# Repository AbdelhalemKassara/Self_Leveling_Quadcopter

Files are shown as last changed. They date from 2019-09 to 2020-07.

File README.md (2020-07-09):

# Self Leveling Quadcopter
As you can tell by the title this project is a self leveling quadcopter that I built using an Arduino Uno. This project is just something that I wanted to try to build for fun and to see if I could make a semi functional drone that has a functional self leveling feature. I have writen 2 versions of the code Manual and SelfLevel. Manual you use the joystick to change the amount of power going to each motor. Self Level you use the joystick to change the tilt angle and the arduino does all the leveling for you.

## Photos and Videos
[Video of the Drone Flying](https://youtu.be/ctLI9JnbgVA)

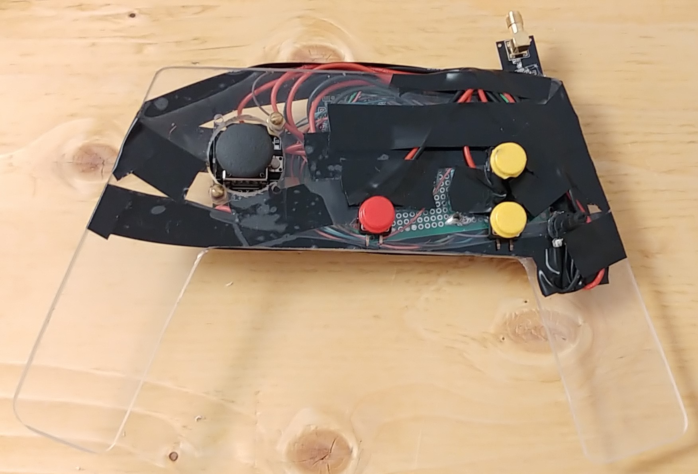
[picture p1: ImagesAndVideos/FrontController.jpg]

>Front of the controller

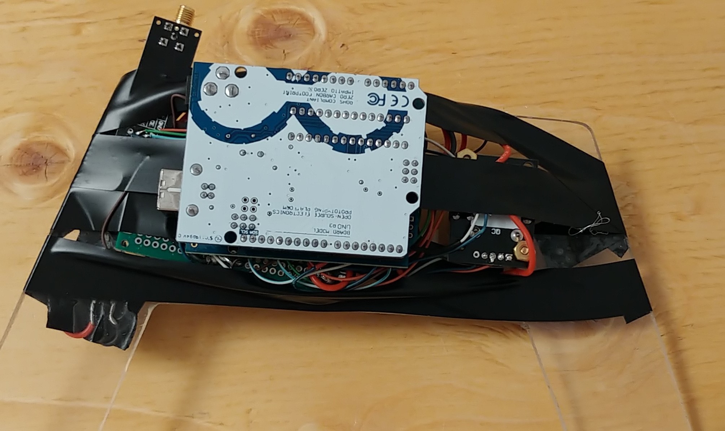
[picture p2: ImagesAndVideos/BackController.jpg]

>Back of the controller

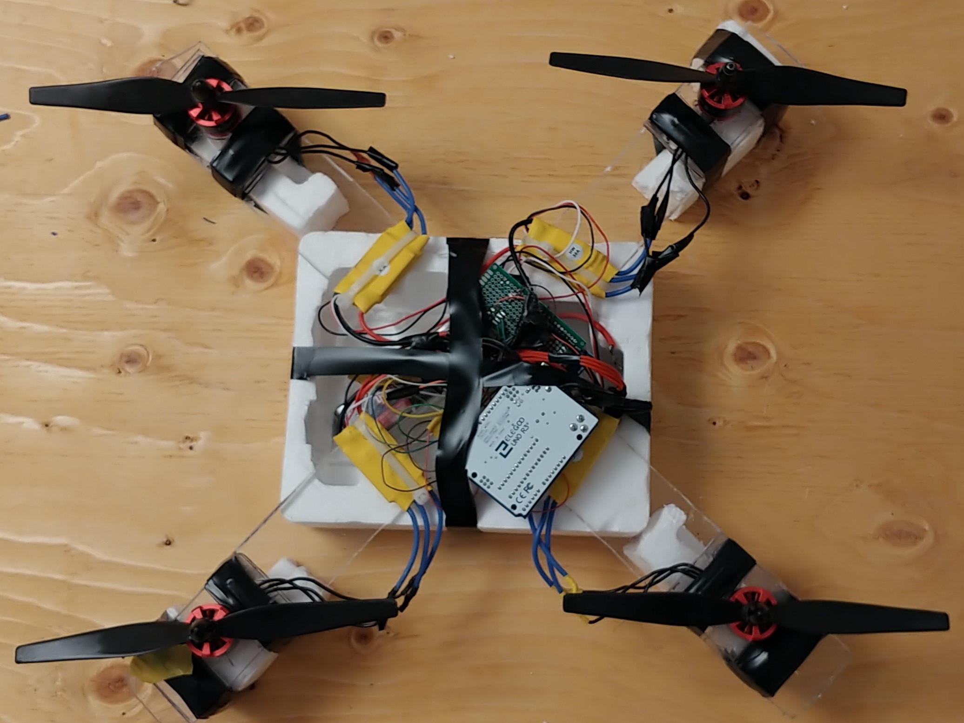
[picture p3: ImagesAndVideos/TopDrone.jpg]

>Top of the drone

Sorry for the mess of Electrical Tape I ran out of Plexi Glass and Screws. Also the frame cracked so I put Electrical Tape over the screws for the motors just in case.

## Getting Started
These instructions will get you a flying drone.

### Prerequisites
#### Parts List
  * 2 Arduinos 
  * 3 10K Resistors
  * 1 10K Potentiometer
  * 1 KY-023 Analog Joystick
  * 3 Push Buttons
  * 1 MPU6050 Gyroscope and Accelerometer
  * 1 Wireless Receivers
  * 1 Wireless Transmitters
  * 4 BLDC Motors 
  * 4 Motor Controllers 
  * 1 3S 40C 2200mah Lipo Battery
  * 1 9V Battery
  * 1 Plexiglass Drone Frame
  * 1 Plexiglass Controller Frame

### Installing
#### Steps
 1. Download the repository.
 1. Using the drawing provided, cut out the drone frame, controller frame, 4 brackets for the motor, and 4 spacers.
 1. Wire up the controller and drone using the schematics provided.
 1. Upolad the code to the arduino. (there are 2 folders Manual and SelfLevel)
 1. Start flying.
 
## Built With 
C++

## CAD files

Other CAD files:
InventorDrawings/Assembly1.dwg
InventorDrawings/controller.dwg
InventorDrawings/GyroSensor.dwg
InventorDrawings/Arduino.dwg
InventorDrawings/CONTROLLER CASE.dwg
InventorDrawings/Propeller.dwg
InventorDrawings/BracketOfTheBracket.dwg
InventorDrawings/CONTROLLER FINAL.dwg
InventorDrawings/battery.dwg
InventorDrawings/drone frame.dwg
InventorDrawings/bracket for drone.dwg
InventorDrawings/OldVersions/Assembly1.0006.dwg
InventorDrawings/OldVersions/battery.0003.dwg
InventorDrawings/OldVersions/drone frame.0001.dwg
InventorDrawings/OldVersions/bracket for drone.0002.dwg
InventorDrawings/OldVersions/controller.0003.dwg
InventorDrawings/OldVersions/Arduino.0006.dwg
InventorDrawings/OldVersions/BracketOfTheBracket.0002.dwg
InventorDrawings/Arduino.ipt
InventorDrawings/Assembly1.iam
InventorDrawings/Assembly1.ipn
InventorDrawings/BracketOfTheBracket.ipt
InventorDrawings/CONTROLLER CASE.ipt
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

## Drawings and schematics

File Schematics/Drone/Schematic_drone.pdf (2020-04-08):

11 | Phase 2 BLDC Motor Controller
11 Phase 2 | BLDC Motor Controller

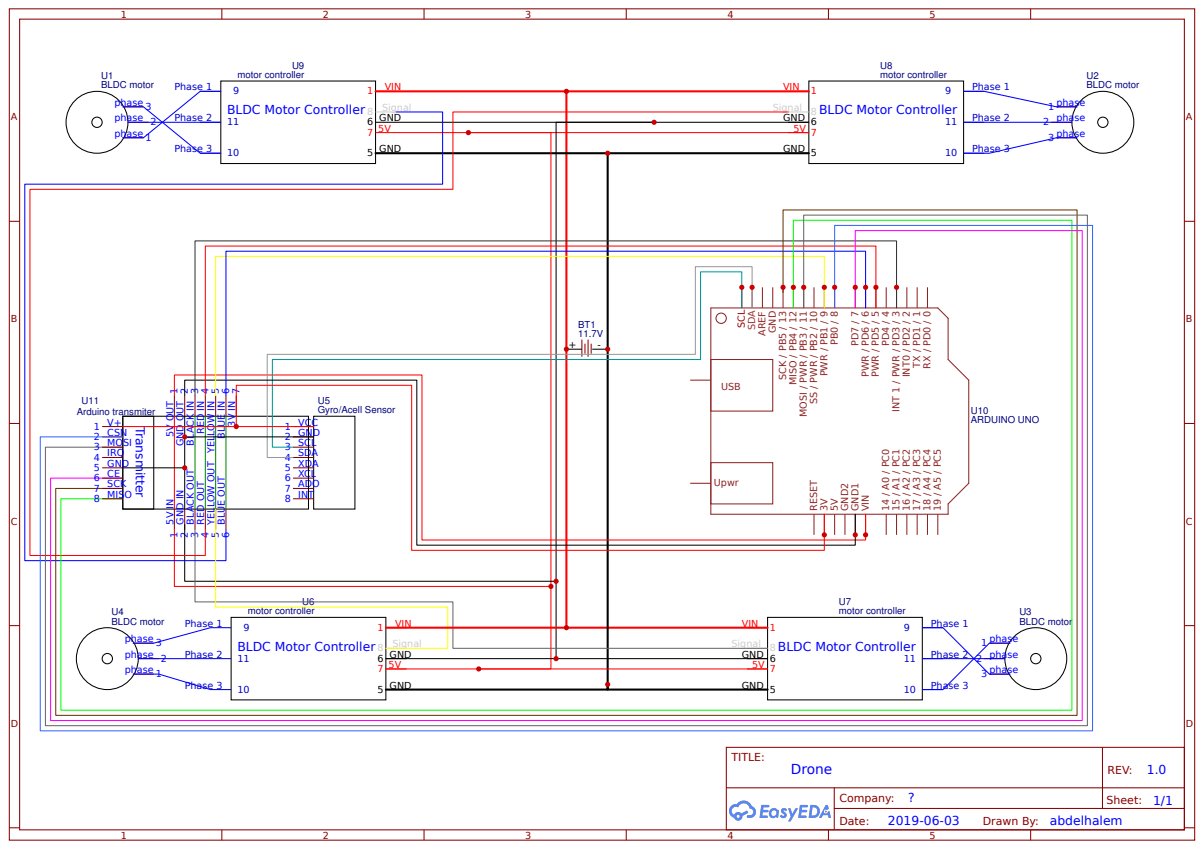
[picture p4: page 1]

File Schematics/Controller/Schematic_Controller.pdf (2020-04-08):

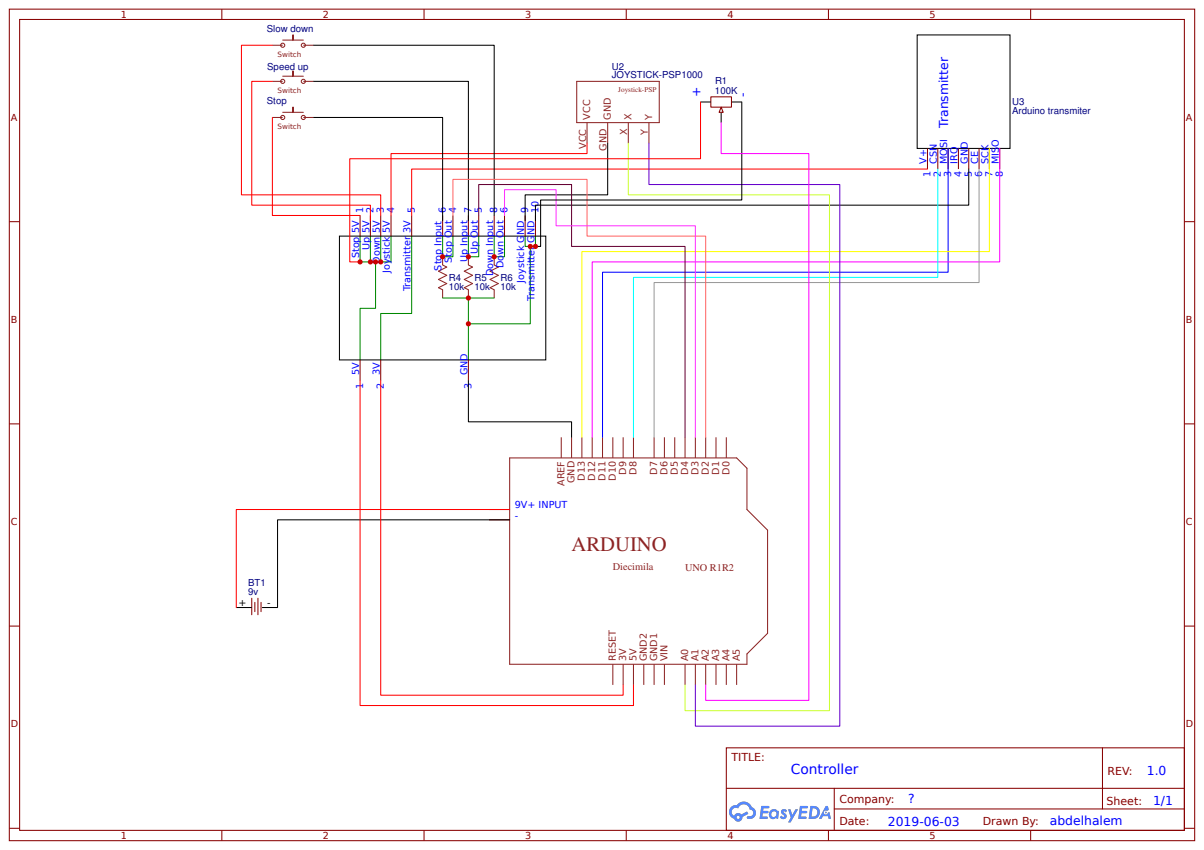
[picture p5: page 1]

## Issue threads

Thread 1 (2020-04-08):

Controller disconnecting

AbdelhalemKassara, 2020-04-08:
The controller for the drone keeps rapidly disconnecting causing the speed of the drone motors to flutter and causing the user to make inaccurate adjustments with the controller leading the drone to crash.

AbdelhalemKassara, 2020-08-08:
The antenna wasn't connected properly when testing.

Closed 2020-04-11.

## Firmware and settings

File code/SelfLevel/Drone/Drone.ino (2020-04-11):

#include<Wire.h>
#include <Servo.h>
#include <SPI.h>
#include <nRF24L01.h>
#include <RF24.h>

RF24 radio(7, 8);
const byte address[6] = "00001";
long TimeSinceLastCon = 0;

// gyro sensor
int GyX, GyY, GyZ;
long AcX, AcY, AcZ, TotalAcc;// try variables with and int
int Tmp;
long GyXOff, GyYOff, GyZOff;
long Timer;
float GyPitch, GyRoll;
boolean set_gyro_angles;
float AccRoll, AccPitch;
float Pitch, Roll;
const int MaxTurnAngle = 30;//stores the max value that the drone can change is angle by

// motors
// front
//put in an array
byte M1Speed; //black FL
byte M2Speed; //red FR
//rear
byte M3Speed; //yellow RL
byte M4Speed; //blue RR

Servo OutM1;
Servo OutM2;
Servo OutM3;
Servo OutM4;

struct DataPackage {
  byte XPos;
  byte YPos;
  byte Throttle;
  bool StopProp;
}; struct DataPackage Data;

bool EStop = false;

void setup() {
  // motors
  OutM1.attach(9, 1000, 2000);
  OutM2.attach(3, 1000, 2000);
  OutM3.attach(5, 1000, 2000);
  OutM4.attach(6, 1000, 2000);
  SetupMotorController();

  //gyro/accel sensor
  Wire.begin();
  setup_mpu_6050_registers();
  OffSetGyro();

  // radio/ contorller
  radio.begin();
  radio.openReadingPipe(0, address);
  radio.setPALevel(RF24_PA_MAX);
  radio.startListening();

  //timer for the 250hz frequency of the program
  Timer = micros();
}

void loop() {
  if (radio.available()) {
    radio.read(&Data, sizeof(DataPackage));
    TimeSinceLastCon = micros();//stores the last time the controllers was connected

  } else {
    SetNutralValForJoyStick();
    if (micros() - TimeSinceLastCon > 5000000) { //if the controller has not been connected in 5 seconds
      //when going down it waits until there is not acceleration in the y axis//create a function for landing
      //call landing function here
      Landing();
    }
  }

  GetPosition();
  GyroAngles();
  Leveling();
  AccelAngles();
  CorrGyDrift();
  CompFilter();
  UpdateSpeed();

  while (micros() - Timer < 4000) {                               //Wait until the Timer reaches 4000us (250Hz) before starting the next loop
    //do nothing unitl the time reaches 4000us for the required 250Hz frequency
  }
  Timer = micros();
}

// functions
void Landing() {
  GetPosition();
  if (AcY > -100) {
    if (Data.Throttle = 0) {
      exit(0);
    } else {
      Data.Throttle--;
    }
  }
  GyroAngles();
  Leveling();
  AccelAngles();
  CorrGyDrift();
  CompFilter();
  UpdateSpeed();

}

void Leveling() {
  if ((abs(GyPitch) > MaxTurnAngle) || (abs(GyRoll) > MaxTurnAngle)) {
    M1Speed = 0;
    M2Speed = 0;
    M3Speed = 0;
    M4Speed = 0;
  }
  else {
    float DistSens = 0.25;//to control the sensitivity of the drone

    float Pitch = (Data.XPos - 128) + (GyPitch / MaxTurnAngle) * 128;
    float Roll  = (Data.YPos - 128) + (GyRoll / MaxTurnAngle) * 128; // adds the speed needed for turning and leveling the drone
    float AvSpeed = map(Data.Throttle, 0, 255, 0, 180 - DistSens * 360);//180 * 2 for the controller and self leveling(180 is the max speed of the motors)
    float Sensitivity = DistSens * Data.Throttle / 510; // 2*255

    M1Speed = (byte)(AvSpeed + ((-Roll + Pitch) * Sensitivity));//put motorspeed in an array
    M2Speed = (byte)(AvSpeed + ((-Roll - Pitch) * Sensitivity));
    M3Speed = (byte)(AvSpeed + ((+Roll + Pitch) * Sensitivity));
    M4Speed = (byte)(AvSpeed + ((+Roll - Pitch) * Sensitivity));
  }
}


void SetNutralValForJoyStick() {
  Data.XPos = 128;
  Data.YPos = 128;
}

void UpdateSpeed() {
  OutM1.write(M1Speed);
  OutM2.write(M2Speed);
  OutM3.write(M3Speed);
  OutM4.write(M4Speed);
}

void SetupMotorController() {
  delay(1000);

  AllMin();
  delay(2000);

  AllMax();
  delay(2000);

  AllMin();
  delay(2000);
}

void AllMax() {
  M1Speed = 180;
  M2Speed = 180;
  M3Speed = 180;
  M4Speed = 180;
  UpdateSpeed();
}

void AllMin() {
  M1Speed = 0;
  M2Speed = 0;
  M3Speed = 0;
  M4Speed = 0;
  UpdateSpeed();

}

void GetPosition() {
  Wire.beginTransmission(0x68);
  Wire.write(0x3B);
  Wire.endTransmission();
  Wire.requestFrom(0x68, 14);
  while (Wire.available() < 14);
  AcX = Wire.read() << 8 | Wire.read();
  AcY = Wire.read() << 8 | Wire.read();
  AcZ = Wire.read() << 8 | Wire.read();
  Tmp = Wire.read() << 8 | Wire.read();
  GyX = Wire.read() << 8 | Wire.read();
  GyY = Wire.read() << 8 | Wire.read();
  GyZ = Wire.read() << 8 | Wire.read();
}

void OffSetGyro() {

  for (int i = 0; i < 2000 ; i ++) {
    GetPosition();
    GyXOff += GyX;
    GyYOff += GyY;
    GyZOff += GyZ;
    delay(3);                                                          //Delay 3us to simulate the 250Hz program loop
  }
  GyXOff /= 2000;
  GyYOff /= 2000;
  GyZOff /= 2000;

}

void setup_mpu_6050_registers() {
  Wire.beginTransmission(0x68);
  Wire.write(0x6B);
  Wire.write(0x00);
  Wire.endTransmission();
  //Configure the accelerometer (+/-8g)
  Wire.beginTransmission(0x68);
  Wire.write(0x1C);
  Wire.write(0x10);
  Wire.endTransmission();
  //Configure the gyro (500dps full scale)
  Wire.beginTransmission(0x68);
  Wire.write(0x1B);
  Wire.write(0x08);
  Wire.endTransmission();
}

void GyroAngles() {
  GyX -= GyXOff;
  GyY -= GyYOff;
  GyZ -= GyZOff;

  //Gyro angle calculations
  //0.0000611 = 1 / (250Hz / 65.5)
  GyPitch += GyX * 0.0000611;
  GyRoll += GyY * 0.0000611;

  //0.000001066 = 0.0000611 * (3.142(PI) / 180degr) The Arduino sin function is in radians
  GyPitch += GyRoll * sin(GyZ * 0.000001066); //output values?? possibly for staying still
  GyRoll -= GyPitch * sin(GyZ * 0.000001066);// output values?? possibly for staying still
}

void AccelAngles() {
  TotalAcc = sqrt((AcX * AcX) + (AcY * AcY) + (AcZ * AcZ));
  //57.296 = 1 / (3.142 / 180)// The Arduino asin function is in radians
  AccPitch = asin((float)AcY / TotalAcc) * 57.296;
  AccRoll = asin((float)AcX / TotalAcc) * -57.296;

  //Place the MPU-6050 spirit level and note the values in the following two lines for calibration
  AccPitch -= -0.90;                                              //Accelerometer calibration value for pitch
  AccRoll -= 0.68;                                               //Accelerometer calibration value for roll
}

void CorrGyDrift() {
  if (set_gyro_angles) {
    GyPitch = GyPitch * 0.9996 + AccPitch * 0.0004;
    GyRoll = GyRoll * 0.9996 + AccRoll * 0.0004;
  }
  else {
    GyPitch = AccPitch;
    GyRoll = AccRoll;
    set_gyro_angles = true;
  }

}

void CompFilter() { // complementary filter
  //To dampen the pitch and roll angles a complementary filter is used
  Pitch = Pitch * 0.9 + GyPitch * 0.1; // output values?? possibly for movemnt
  Roll = Roll * 0.9 + GyRoll * 0.1; // output values??possibly for movemnt
}

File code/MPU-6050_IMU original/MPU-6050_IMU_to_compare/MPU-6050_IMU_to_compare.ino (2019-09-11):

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

  ///////////////////////////////////////////////////////////////////////////////////////
  //Support
  ///////////////////////////////////////////////////////////////////////////////////////
  Website: http://www.brokking.net/imu.html
  Youtube: https://youtu.be/4BoIE8YQwM8
  Version: 1.0 (May 5, 2016)

  ///////////////////////////////////////////////////////////////////////////////////////
  //Connections
  ///////////////////////////////////////////////////////////////////////////////////////
  Power (5V) is provided to the Arduino pro mini by the FTDI programmer

  Gyro - Arduino pro mini
  VCC  -  5V
  GND  -  GND
  SDA  -  A4
  SCL  -  A5

  LCD  - Arduino pro mini
  VCC  -  5V
  GND  -  GND
  SDA  -  A4
  SCL  -  A5
*//////////////////////////////////////////////////////////////////////////////////////

//Include LCD and I2C library
#include <Wire.h>

//Declaring some global variables
int gyro_x, gyro_y, gyro_z;// has angles
long acc_x, acc_y, acc_z, acc_total_vector; // has angles
int temperature;
long gyro_x_cal, gyro_y_cal, gyro_z_cal; //offset
long Timer;// done
float angle_pitch, angle_roll;
boolean set_gyro_angles;
float angle_roll_acc, angle_pitch_acc;
float angle_pitch_output, angle_roll_output;

//Initialize the LCD library


void setup() {
  Wire.begin();                                                        //Start I2C as master
  Serial.begin(57600);                                               //Use only for debugging

  setup_mpu_6050_registers();                                          //Setup the registers of the MPU-6050 (500dfs / +/-8g) and start the gyro

  //Set the LCD cursor to position to position 0,1
  for (int cal_int = 0; cal_int < 2000 ; cal_int ++) {                 //Run this code 2000 times
    read_mpu_6050_data();                                              //Read the raw acc and gyro data from the MPU-6050
    gyro_x_cal += gyro_x;                                              //Add the gyro x-axis offset to the gyro_x_cal variable
    gyro_y_cal += gyro_y;                                              //Add the gyro y-axis offset to the gyro_y_cal variable
    gyro_z_cal += gyro_z;                                              //Add the gyro z-axis offset to the gyro_z_cal variable
    delay(3);                                                          //Delay 3us to simulate the 250Hz program loop
  }
  gyro_x_cal /= 2000;                                                  //Divide the gyro_x_cal variable by 2000 to get the avarage offset
  gyro_y_cal /= 2000;                                                  //Divide the gyro_y_cal variable by 2000 to get the avarage offset
  gyro_z_cal /= 2000;                                                  //Divide the gyro_z_cal variable by 2000 to get the avarage offset


  Timer = micros();                                               //Reset the loop timer
}

void loop() {

  read_mpu_6050_data();                                                //Read the raw acc and gyro data from the MPU-6050
GyroAngles();
  Serial.println(angle_pitch);
  Serial.println(angle_roll);
AccelAngles();
CorrGyDrift();
CompFilter();

  while (micros() - Timer < 4000);                                //Wait until the loop_timer reaches 4000us (250Hz) before starting the next loop
  Timer = micros();                                               //Reset the loop timer
}


void read_mpu_6050_data() {                                            //Subroutine for reading the raw gyro and accelerometer data
  Wire.beginTransmission(0x68);                                        //Start communicating with the MPU-6050
  Wire.write(0x3B);                                                    //Send the requested starting register
  Wire.endTransmission();                                              //End the transmission
  Wire.requestFrom(0x68, 14);                                          //Request 14 bytes from the MPU-6050
  while (Wire.available() < 14);                                       //Wait until all the bytes are received
  acc_x = Wire.read() << 8 | Wire.read();                              //Add the low and high byte to the acc_x variable
  acc_y = Wire.read() << 8 | Wire.read();                              //Add the low and high byte to the acc_y variable
  acc_z = Wire.read() << 8 | Wire.read();                              //Add the low and high byte to the acc_z variable
  temperature = Wire.read() << 8 | Wire.read();                        //Add the low and high byte to the temperature variable
  gyro_x = Wire.read() << 8 | Wire.read();                             //Add the low and high byte to the gyro_x variable
  gyro_y = Wire.read() << 8 | Wire.read();                             //Add the low and high byte to the gyro_y variable
  gyro_z = Wire.read() << 8 | Wire.read();                             //Add the low and high byte to the gyro_z variable

}



void setup_mpu_6050_registers() {
  //Activate the MPU-6050
  Wire.beginTransmission(0x68);                                        //Start communicating with the MPU-6050
  Wire.write(0x6B);                                                    //Send the requested starting register
  Wire.write(0x00);                                                    //Set the requested starting register
  Wire.endTransmission();                                              //End the transmission
  //Configure the accelerometer (+/-8g)
  Wire.beginTransmission(0x68);                                        //Start communicating with the MPU-6050
  Wire.write(0x1C);                                                    //Send the requested starting register
  Wire.write(0x10);                                                    //Set the requested starting register
  Wire.endTransmission();                                              //End the transmission
  //Configure the gyro (500dps full scale)
  Wire.beginTransmission(0x68);                                        //Start communicating with the MPU-6050
  Wire.write(0x1B);                                                    //Send the requested starting register
  Wire.write(0x08);                                                    //Set the requested starting register
  Wire.endTransmission();                                              //End the transmission
}
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

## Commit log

2019-09-02 added project to the repository
    [Arduino.0006.dwg, Arduino.dwg, Arduino.ipt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]
2019-09-11 added files needed to fix code
    [Drone_gyrotest_code.ino, MPU-6050_IMU.ino, MPU-6050_IMU_to_compare.ino]
2019-09-11 found problem in code
    [Drone_gyrotest_code.ino, Drone_gyrotest_codeasdasdf.ino, MPU-6050_IMU_to_compare.ino]
2020-02-04 reorganised the files
    [Arduino.0006.dwg, Arduino.dwg, Arduino.ipt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]
2020-03-04 started checking if the button to stop the drone has been pressed
2020-03-13 started adding in the ultrasonic sensor
2020-03-19 fixed some of the file names
    [Abdel_s_Drone_10_Time_ProjectV3.ino]
2020-03-20 fixed mistakes from the last commit
    [Drone_gyrotest_code.ino, Drone_gyrotest_codeasdasdf.ino, another_test.ino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]
2020-03-20 finished redoing the wiring and testing of the controller
2020-03-20 edited the test code for wireless transmission
2020-04-01 fixed some problems with the controller and wrote some code to test the controller
    [ManualRecieverTest.ino]
2020-04-01 cannot use the ultrasonic sensor because speed of sound is too slow
    [DistUsingThermAndUltra.ino]
2020-04-06 fixed some of the mistakes where the drone was not using the full power on the motors and started writing the emergency proceedure for the self leveling code
2020-04-07 fixed the names of some files
    [Arduino.0006.dwg, Arduino.dwg, Arduino.ipt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]
2020-04-08 updated the schematic for the drone and controller
2020-04-09 fixed the file names
    [Controller.ino, Drone.ino]
